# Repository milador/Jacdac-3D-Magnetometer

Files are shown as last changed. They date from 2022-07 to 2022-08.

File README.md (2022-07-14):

# Jacdac-3D-Magnetometer
A <a href="https://microsoft.github.io/jacdac-docs/">Jacdac</a> 3D-Magnetometer Module based on <a href="https://www.infineon.com/cms/en/product/sensor/magnetic-sensors/magnetic-position-sensors/3d-magnetics/tlv493d-a1b6/">TLV493D</a> 3-axis magnetometer sensor.

## Top View: 

<p align="center">
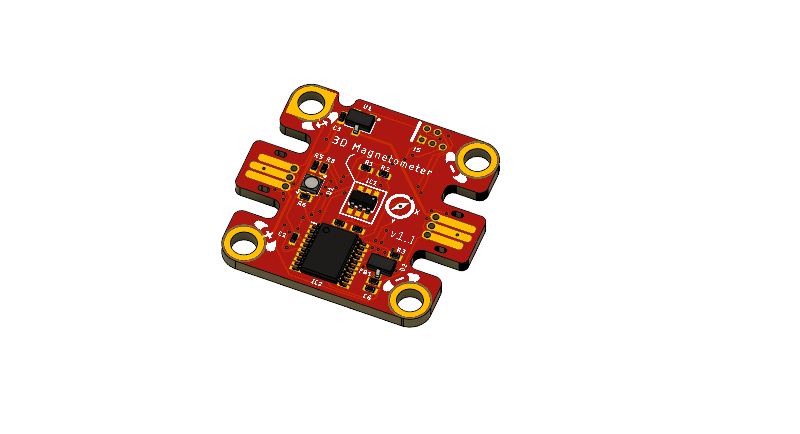
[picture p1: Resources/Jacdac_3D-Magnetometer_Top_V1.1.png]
Jacdac-3D-Magnetometer Top

</p>

## Bottom View:

<p align="center">
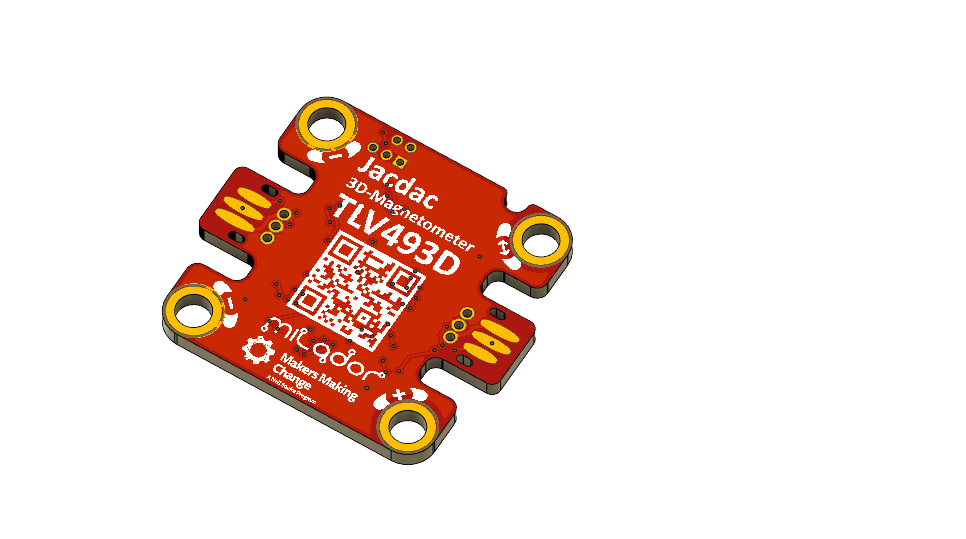
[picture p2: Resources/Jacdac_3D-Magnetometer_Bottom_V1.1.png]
Jacdac-3D-Magnetometer Bottom

</p>

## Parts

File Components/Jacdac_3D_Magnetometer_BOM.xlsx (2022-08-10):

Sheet: RevA
Index | Quantity | Item | Value | Digikey/Mouser/LCSC Part Number | Manufacturer Part Number | Description | Unit Price (CAD) | Total Price (CAD) | Link
1 | 2 | R1,R2 | 30R | C136965 | RT0603BRD0730RL | RES 30 OHM 1% 1/8W 0603 | 0.0344 | 0.0688 | https://lcsc.com/product-detail/Chip-span-style-background-color-ff0-Resistor-span-Surface-Mount_YAGEO-RT0603BRD0730RL_C136965.html
2 | 1 | R3 | 150R | C319859 | AR03BTCX1500 | RES 150 OHM 1% 1/8W 0603 | 0.037 | 0.037 | https://lcsc.com/product-detail/Chip-Resistor-Surface-Mount_Viking-Tech-AR03BTCX1500_C319859.html
3 | 1 | R4 | 220R | C318124 | AR03BTCX2200 | RES SMD 220 OHM 5% 1/8W 0603 | 0.029 | 0.029 | https://lcsc.com/product-detail/Chip-Resistor-Surface-Mount_Viking-Tech-AR03BTCX2200_C318124.html
4 | 2 | R5,R6 | 4.7K | C700513 | RT0603FRE074K7L | RES 4.7K OHM 1% 1/8W 0603 | 0.0089 | 0.0178 | https://lcsc.com/product-detail/Chip-Resistor-Surface-Mount_YAGEO-RT0603FRE074K7L_C700513.html
5 | 1 | U1 | STM32F042F6P6 | C81000 | STM32F042F6P6 | IC MCU 32BIT 32KB FLASH 20TSSOP | 7.33 | 7.33 | https://lcsc.com/product-detail/ST-Microelectronics_STMicroelectronics-STM32F042F6P6_C81000.html
6 | 1 | U2 | NCP114ASN330T1G | NCP114ASN330T1GOSCT-ND/C457666 | NCP114ASN330T1G | IC REG LINEAR 3.3V 300MA 5TSOP | 0.2352 | 0.2352 | https://lcsc.com/product-detail/Linear-Voltage-Regulators-LDO_onsemi-NCP114ASN330T1G_C457666.html (https://www.digikey.ca/en/products/detail/on-semiconductor/NCP114ASN330T1G/6560605)
7 | 1 | U3 | TLV493DA1B6 | 726-TLV493DA1B6HTSA2 /C126688 | TLV493DA1B6HTSA2 | 3D-MAGNETOMETER | 3.27 | 3.27 | https://www.mouser.ca/ProductDetail/Infineon-Technologies/TLV493DA1B6HTSA2?qs=0DP5yvOrqYnbdRXsuslLCg%3D%3D | https://lcsc.com/product-detail/Magnetic-Sensors_Infineon-Technologies-TLV493DA1B6HTSA2_C126688.html
8 | 1 | U4 | BAT54S,235 | C503463 | BAT54S,235 | DIODE ARRAY SCHOTTKY 30V SOT23 | 0.03 | 0.03 | https://lcsc.com/product-detail/Pre-ordered-transistors_Nexperia-BAT54S-235_C503463.html
9 | 3 | C1,C3,C5 | 1uF | C519560 | CC0603JRX7R7BB105 | CAP CER 1UF 16V X5R 0603 | 0.0284 | 0.0852 | https://lcsc.com/product-detail/Multilayer-Ceramic-Capacitors-MLCC-SMD-SMT_YAGEO-CC0603JRX7R7BB105_C519560.html
10 | 1 | C2 | 33pF | C519485 | CC0603FRNPO9BN330 | CAP CER 0603 33PF 50V ULTRA STAB | 0.0177 | 0.0177 | https://lcsc.com/product-detail/Multilayer-Ceramic-Capacitors-MLCC-SMD-SMT_YAGEO-CC0603FRNPO9BN330_C519485.html
11 | 1 | C4 | 0.1 µF | C1845757 | C0603C104M3RACAUTO | CAP CER 0.1UF 25V X7R 0603 | 0.018 | 0.018 | https://lcsc.com/product-detail/Multilayer-Ceramic-Capacitors-MLCC-SMD-SMT_KEMET-C0603C104M3RACAUTO_C1845757.html
12 | 1 | FB1 | 800mA 1kR | C193411 | MPZ1608S102ATD25 | FERRITE BEAD 1 KOHM 0603 1LN | 0.028 | 0.028 | https://lcsc.com/product-detail/Ferrite-Beads_TDK-MPZ1608S102ATD25_C193411.html
13 | 2 | D1,D2 | RCLAMP0521P | C2827711 | RCLAMP0521P | TVS DIODE 5VWM 25VC SLP1006P2 | 0.0445 | 0.089 | https://lcsc.com/product-detail/ESD-Protection-Devices_TECH-PUBLIC-RCLAMP0521P_C2827711.html
14 | 1 | LED (D3) | RGB LED | 516-1795-1-ND /C97504 | HSMF-C114 | LED RGB DIFFUSED CHIP SMD | 2.63 | 2.63 | https://www.digikey.ca/en/products/detail/broadcom-limited/HSMF-C114/1235344
 |  |  |  |  |  |  | Total Price: | 13.8857

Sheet: RevB
Index | Quantity | Item | Value | Digikey/Mouser/LCSC Part Number | Manufacturer Part Number | Description | Unit Price (CAD) | Total Price (CAD) | Link
1 | 2 | R1,R2 | 10K | C2902636 | ARG02BTC1002 | RES 10K OHM 0.1% 0402 | 0.0233 | 0.0466 | https://lcsc.com/product-detail/Chip-Resistor-Surface-Mount_Viking-Tech-ARG02BTC1002_C2902636.html
2 | 2 | R3,R5 | 220R | C317911 | AR02BTC2200 | RES 220 OHM 0.1% 0402 | 0.0272 | 0.0544 | https://lcsc.com/product-detail/Chip-Resistor-Surface-Mount_Viking-Tech-AR02BTC2200_C317911.html
3 | 1 | R6 | 470R | C482182 | CRCW0402470RFKED | RES 470 OHM 1% 0402 | 0.0394 | 0.0394 | https://lcsc.com/product-detail/Chip-Resistor-Surface-Mount_Vishay-Intertech-CRCW0402470RFKED_C482182.html
4 | 1 | R8 | 150R | C319855 | AR02BTC1500 | RES 150 OHM 0.1% 0402 | 0.032 | 0.032 | https://lcsc.com/product-detail/Chip-Resistor-Surface-Mount_Viking-Tech-AR02BTC1500_C319855.html
5 | 1 | IC1 | TLV493DA1B6 | TLV493DA1B6HTSA2/C126688 | TLV493DA1B6HTSA2 | 3D-MAGNETOMETER | 3.27 | 3.27 | https://www.arrow.com/en/products/tlv493da1b6htsa2/infineon-technologies-ag?q=TLV493DA1B6HTSA2 | https://lcsc.com/product-detail/Magnetic-Sensors_Infineon-Technologies-TLV493DA1B6HTSA2_C126688.html
6 | 1 | IC2 | STM32G030F6P6 | C724040 | STM32G030F6P6 | IC MCU 32BIT 32KB FLASH 20TSSOP | 0.98 | 0.98 | https://lcsc.com/product-detail/ST-Microelectronics_STMicroelectronics-STM32G030F6P6_C724040.html
7 | 1 | U1 | XC6206-3.3V | C2891841 | XC6206-3.3V | IC REG LINEAR 3.3V SOT-23-3L | 0.0614 | 0.0614 | https://lcsc.com/product-detail/Linear-Voltage-Regulators-LDO_YONGYUTAI-XC6206-3-3V_C2891841.html
8 | 2 | C1,C4 | 100nF | C361202 | C1005X5R1H104KT000F | 50V 100nF X5R ±10% 0402 | 0.0227 | 0.0454 | https://lcsc.com/product-detail/Multilayer-Ceramic-Capacitors-MLCC-SMD-SMT_TDK-C1005X5R1H104KT000F_C361202.html
9 | 2 | C2,C3 | 4.7uF | C342983 | C1005X5R1A475KTJ00E | 10V 4.7uF X5R ±10% 0402 | 0.0476 | 0.0952 | https://lcsc.com/product-detail/Multilayer-Ceramic-Capacitors-MLCC-SMD-SMT_TDK-C1005X5R1A475KTJ00E_C342983.html
10 | 1 | C6 | 33pF | C76905 | GJM1555C1H330GB01D | 50V 33pF C0G ±2% 0402 | 0.0335 | 0.0335 | https://lcsc.com/product-detail/Multilayer-Ceramic-Capacitors-MLCC-SMD-SMT_Murata-Electronics-GJM1555C1H330GB01D_C76905.html
11 | 1 | FB1 | 1kΩ @ 100MHz | C275423 | MMZ1005S102ET000 | FERRITE BEAD 250mA 1 1Ω 1kΩ@100MHz ±25% 0402 | 0.0308 | 0.0308 | https://lcsc.com/product-detail/Ferrite-Beads_TDK-MMZ1005S102ET000_C275423.html
12 | 1 | D1 | RGB LED | C108793 | FM-B2020RGBA-HG | LED RGB CHIP SMD | 0.0289 | 0.0289 | https://lcsc.com/product-detail/Light-Emitting-Diodes-LED_Foshan-NationStar-Optoelectronics-FM-B2020RGBA-HG_C108793.html
13 | 1 | D2 | BAT54S | C328578 | BAT54S,23 | DIODE ARRAY SCHOTTKY 30V SOT23 | 0.0245 | 0.0245 | https://lcsc.com/product-detail/Schottky-Barrier-Diodes-SBD_Foshan-Blue-Rocket-Elec-BAT54S_C328578.html
 |  |  |  |  |  |  | Total Price: | 4.7421

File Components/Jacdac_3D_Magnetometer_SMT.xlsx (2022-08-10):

Item | Additional Information | Cost
PCB (Jacdac 3D Magnetometer)
PCB fabrication |  | $4.00
Remove order number |  | $1.66
Confirm production file |  | $0.54
SMT
Components | Global Sourcing not included ( Digikey, Mouser) | $9.93
Global Sourcing Components | 5 X $0.8853 (TLV493DA1B6HTSA2) | $4.43
Extended Components fee | $3 labour fee to replace each part in the machine | $38.09
SMT Assembly | $0.0017 per solder joint | $0.97
Setup fee |  | $8.00
Stencil |  | $1.50
Confirm parts placement |  | $0.46
 | Total | $69.58
 | Charged | $69.12

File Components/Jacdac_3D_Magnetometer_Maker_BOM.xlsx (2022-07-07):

Index | Quantity | Item | Value | Digikey/Mouser Part Number | Manufacturer Part Number | Description | Unit Price (CAD) | Total Price (CAD) | Link
1 | 2 | R1,R2 | 30R | 311-30.0CRCT-ND | RC0805FR-0730RL | RES 30 OHM 1% 1/8W 0805 | 0.15 | 0.3 | https://www.digikey.ca/en/products/detail/yageo/RC0805FR-0730RL/727842
2 | 1 | R3 | 150R | 541-CRCW0805150RFKEACCT-ND | CRCW0805150RFKEAC | RES 150 OHM 1% 1/8W 0805 | 0.15 | 0.15 | https://www.digikey.ca/en/products/detail/vishay-dale/CRCW0805150RFKEAC/7922303
3 | 1 | R4 | 220R | 541-CRCW0805220RJNEBCT-ND | CRCW0805220RJNEB | RES SMD 220 OHM 5% 1/8W 0805 | 0.15 | 0.15 | https://www.digikey.ca/en/products/detail/vishay-dale/CRCW0805220RJNEB/5074408
4 | 2 | R5,R6 | 4.7K | 311-4.7KARCT-ND | RC0805JR-074K7L | RES 4.7K OHM 5% 1/8W 0805 | 0.15 | 0.3 | https://www.digikey.ca/en/products/detail/yageo/RC0805JR-074K7L/728327
5 | 1 | U1 | STM32F042F6P6 | 497-17344-ND | STM32F042F6P6 | IC MCU 32BIT 32KB FLASH 20TSSOP | 4.66 | 4.66 | https://www.digikey.ca/en/products/detail/stmicroelectronics/STM32F042F6P6/5268189
6 | 1 | U2 | NCP114ASN330T1G | NCP114ASN330T1GOSCT-ND | NCP114ASN330T1G | IC REG LINEAR 3.3V 300MA 5TSOP | 0.57 | 0.57 | https://www.digikey.ca/en/products/detail/on-semiconductor/NCP114ASN330T1G/6560605
7 | 1 | U3 | TLV493DA1B6 | 726-TLV493DA1B6HTSA2 | TLV493DA1B6HTSA2 | 3D-MAGNETOMETER | 3.27 | 3.27 | https://www.mouser.ca/ProductDetail/Infineon-Technologies/TLV493DA1B6HTSA2?qs=0DP5yvOrqYnbdRXsuslLCg%3D%3D
8 | 1 | U4 | BAT54S,235 | 1727-1868-1-ND | BAT54S,235 | DIODE ARRAY SCHOTTKY 30V SOT23 | 0.2 | 0.2 | https://www.digikey.ca/en/products/detail/nexperia-usa-inc/BAT54S-235/1232122
9 | 3 | C1,C3,C5 | 1uF | 478-1249-1-ND | 0603YD105KAT2A | CAP CER 1UF 16V X5R 0603 | 0.18 | 0.54 | https://www.digikey.ca/en/products/detail/avx-corporation/0603YD105KAT2A/563359
10 | 1 | C2 | 33pF | 399-C0603C330M5HAC7867CT-ND | C0603C330M5HAC7867 | CAP CER 0603 33PF 50V ULTRA STAB | 0.14 | 0.14 | https://www.digikey.ca/en/products/detail/kemet/C0603C330M5HAC7867/7947133
11 | 1 | C4 | 0.1 µF | 478-3755-1-ND | 08053C104KAT2A | CAP CER 0.1UF 25V X7R 0805 | 0.14 | 0.14 | https://www.digikey.ca/en/products/detail/avx-corporation/08053C104KAT2A/1116281?
12 | 1 | FB1 | 800mA 1kR | 445-175021-1-ND | KPZ1608SHR102ATD25 | FERRITE BEAD 1 KOHM 0603 1LN | 0.3 | 0.3 | https://www.digikey.ca/en/products/detail/tdk-corporation/KPZ1608SHR102ATD25/7104424
13 | 1 | LED (D1) | RGB LED | 516-1795-1-ND | HSMF-C114 | LED RGB DIFFUSED CHIP SMD | 2.63 | 2.63 | https://www.digikey.ca/en/products/detail/broadcom-limited/HSMF-C114/1235344
 |  |  |  |  |  |  | Total Price: | 13.35

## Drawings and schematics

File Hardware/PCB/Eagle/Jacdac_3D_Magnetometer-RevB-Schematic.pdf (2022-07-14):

# GND GND 1k@¹⁰⁰MHz VCC

# JD5V VCC

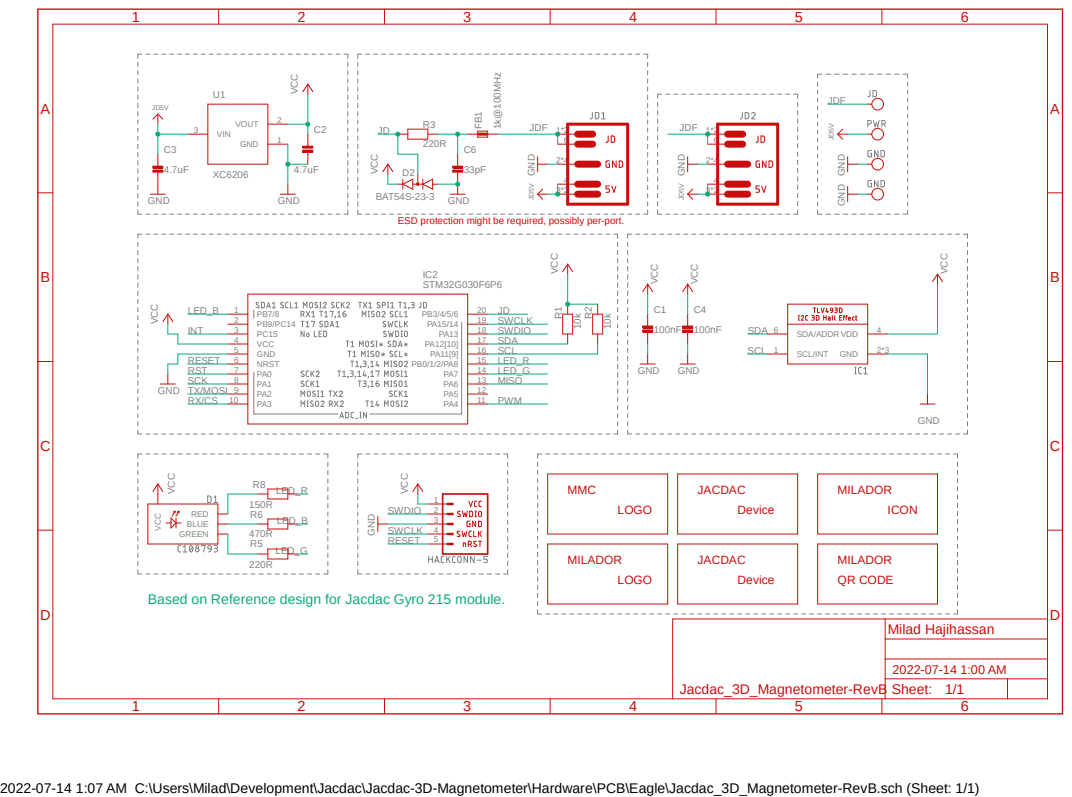
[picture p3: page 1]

ESD protection might be required, possibly per-port.

Based on Reference design for Jacdac Gyro 215 module.

2022-07-14 1:07 AM C:\Users\Milad\Development\Jacdac\Jacdac-3D-Magnetometer\Hardware\PCB\Eagle\Jacdac_3D_Magnetometer-RevB.sch (Sheet: 1/1)

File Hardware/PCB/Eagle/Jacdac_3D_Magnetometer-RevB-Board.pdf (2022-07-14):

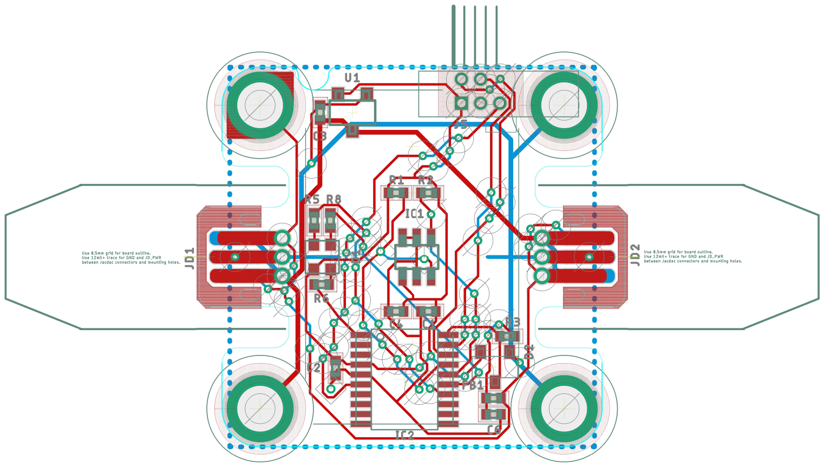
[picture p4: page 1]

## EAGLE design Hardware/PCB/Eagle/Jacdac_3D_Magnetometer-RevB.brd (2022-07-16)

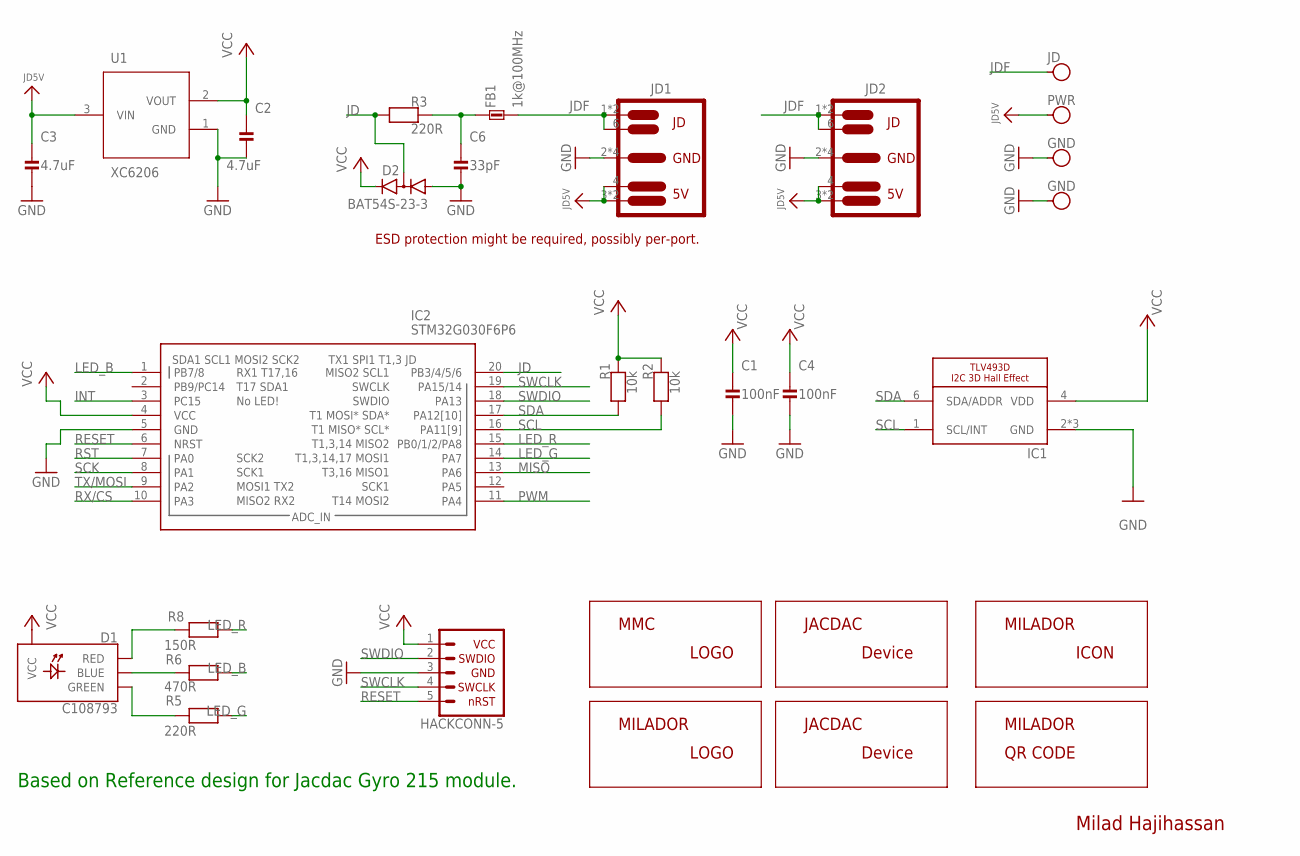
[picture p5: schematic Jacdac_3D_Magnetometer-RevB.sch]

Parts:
C1, C4: 100nF; 0402
C2, C3: 4.7uF; 0402
C6: 33pF; 0402
D1: C108793; LED-RGB-2121
D2: BAT54S-23-3; SOT23-3
FB1: 1k@100MHz; 0402
IC1: TLV493D; SOT23-6
IC2: STM32G030F6P6; SOP65P640X120-20N
J1: JD; M3-HOLE-DATA
J2: PWR; M3-HOLE-PWR
J3, J4: GND; M3-HOLE-GND
J5: HACK-CONNECT-5; HC5-22-62
JD1, JD2: JACDAC-EDGE-OUTIE; JD-EDGE-OUTIE
LABEL_DEVICE: MILADOR-JACDAC-DEVICE-MAGNETOMETER; JACDAC-3D-MAGNETOMETER
LABEL_ICON: MILADOR-ICON-MAG; MILADOR_ICON_MAGNETOMETER
LABEL_LOGO1: MILADOR-LOGO-SM; MILADOR_LOGO2
LABEL_LOGO2: MMC_LOGO-XSM; MMC_X-SMALL_LOGO
LABEL_QRCODE: MILADOR-QR-CODE-JACDAC-MAGNETOMETER; MILADOR_QR_JACDAC_MAGNETOMETER
LABEL_TLV493D: MILADOR-JACDAC-DEVICE-TLV493D; JACDAC-TLV493D
R1, R2: 10k; 0402
R3, R5: 220R; 0402
R6: 470R; 0402
R8: 150R; 0402
U1: XC6206; SOT23-3-W

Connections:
GND: C1.2, C2.2, C3.2, C4.2, C6.2, D2.1 (A1), IC1.2 (GND), IC1.3 (GND), IC1.5 (GND), IC2.5 (GND), J3.H, J4.H, J5.3 (GND), JD1.2 (1), JD1.5 (1), JD1.P$2 (1), JD1.P$4 (1), JD2.2 (1), JD2.5 (1), JD2.P$2 (1), JD2.P$4 (1), U1.1 (GND)
INT: IC2.3 (PC15)
JD: D2.3 (C1A2), IC2.20 (PB3/4/5/6), R3.1
JD5V: C3.1, J2.H, JD1.3, JD1.4, JD1.P$1 (3), JD2.3, JD2.4, JD2.P$1 (3), U1.3 (VIN)
JDF: FB1.2, J1.H, JD1.1 (2), JD1.6, JD1.P$3 (2), JD2.1 (2), JD2.6, JD2.P$3 (2)
LED_B: IC2.1 (PB7/8), R6.1
LED_G: IC2.14 (PA7), R5.1
LED_R: IC2.15 (PB0/1/2/PA8), R8.1
MISO: IC2.13 (PA6)
unnamed: C6.1, FB1.1, R3.2
unnamed: D1.B- (BLUE), R6.2
unnamed: D1.R- (RED), R8.2
unnamed: D1.G- (GREEN), R5.2
PWM: IC2.11 (PA4)
RESET: IC2.6 (NRST), J5.5 (NRST)
RST: IC2.7 (PA0)
RX/CS: IC2.10 (PA3)
SCK: IC2.8 (PA1)
SCL: IC1.1 (SCL/INT), IC2.16 (PA11[9]), R2.1
SDA: IC1.6 (SDA/ADDR), IC2.17 (PA12[10]), R1.1
SWCLK: IC2.19 (PA15/14), J5.4 (SWCLK)
SWDIO: IC2.18 (PA13), J5.2 (SWDIO)
TX/MOSI: IC2.9 (PA2)
VCC: C1.1, C2.1, C4.1, D1.PLUS (VCC), D2.2 (C2), IC1.4 (VDD), IC2.4 (VCC), J5.1 (VCC), R1.2, R2.2, U1.2 (VOUT)

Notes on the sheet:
Based on Reference design for Jacdac Gyro 215 module.
ESD protection might be required, possibly per-port.
Milad Hajihassan

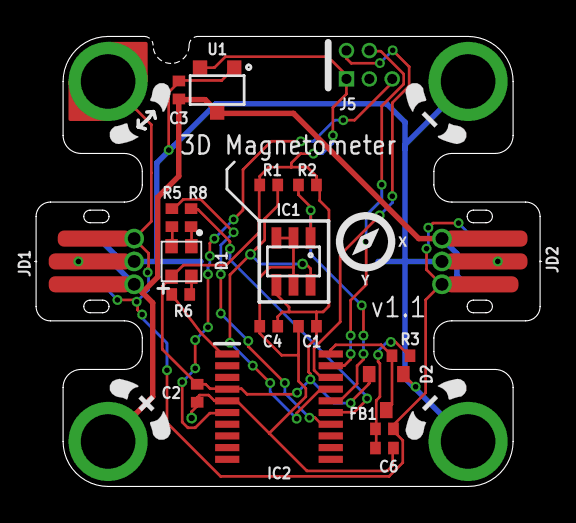
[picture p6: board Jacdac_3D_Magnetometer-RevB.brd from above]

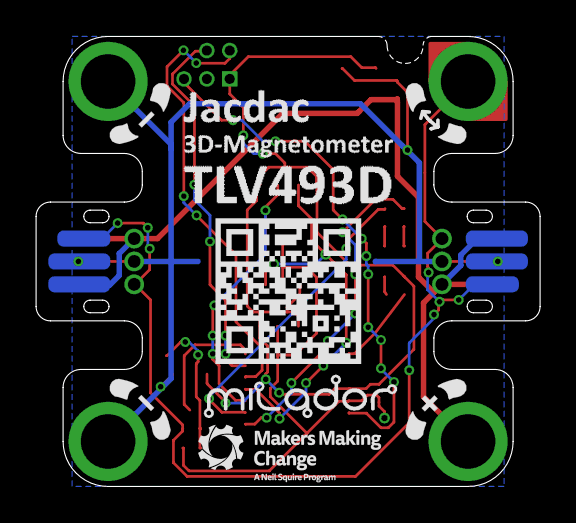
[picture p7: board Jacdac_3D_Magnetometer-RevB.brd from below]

Board: 2 copper layers, 28.0 x 25.0 mm, 30 parts (5 on the bottom side), 17 nets.

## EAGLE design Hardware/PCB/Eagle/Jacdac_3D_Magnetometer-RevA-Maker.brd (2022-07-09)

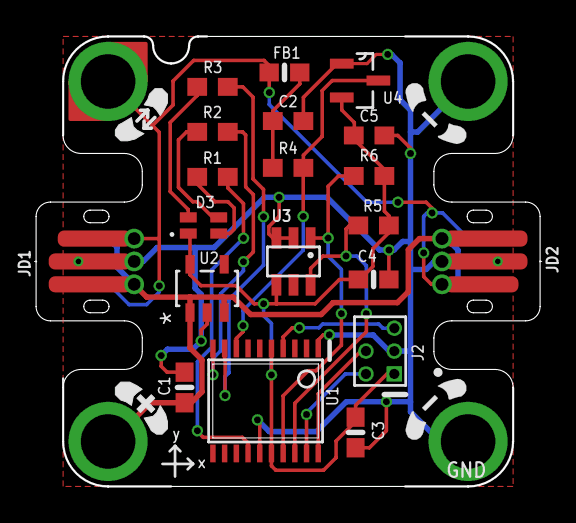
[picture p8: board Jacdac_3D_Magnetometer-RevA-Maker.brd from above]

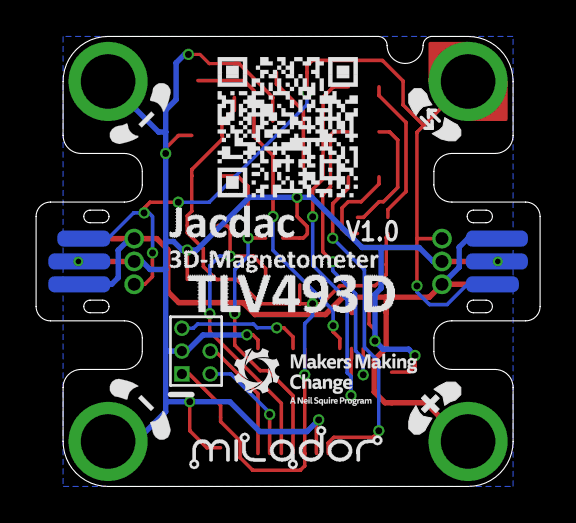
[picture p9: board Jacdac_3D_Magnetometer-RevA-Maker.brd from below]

Board: 2 copper layers, 28.0 x 25.0 mm, 29 parts (5 on the bottom side), 17 nets.

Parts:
C1, C3: 1uF; 0603-NO
C2: 33pF; 0603
C4: 0.1uF; 0603-NO
C5: 1uF; 0603
D3: LED-HSMF-C114; DIOSC160X150X35-4N
FB1: 800mA 1kR; 0603-NO
J2: SWD-ADAPTER-; SWD-ADAPTER
J3: 5V; M3-HOLE-PWR-OUTL
J4: DATA; M3-HOLE-DATA-NOTCH
J5, J6: GND; M3-HOLE-GND
JD1, JD2: JACDAC-EDGE-OUTIE; JD-EDGE-OUTIE
LABEL_JACDAC_PS: MILADOR-JACDAC-DEVICE-MAGNETOMETER; JACDAC-3D-MAGNETOMETER
LABEL_MILADOR: MILADOR-LOGO-; MILADOR_LOGO1
LABEL_QR_CODE: MILADOR-QR-CODE-JACDAC-MAGNETOMETER; MILADOR_QR_JACDAC_MAGNETOMETER
LABEL_TLV493D: MILADOR-JACDAC-DEVICE-TLV493D; JACDAC-TLV493D
MMC_LOGO: MMC_LOGO-XSM; MMC_X-SMALL_LOGO
R1, R2: 30; 0603
R3: 150; 0603
R4: 220; 0603
R5, R6: 4.7K; 0603
U1: STM32F042F6P6; TSSOP20
U2: NCP114ASN330T1G; TSOP-5_ONS
U3: TLV493D; SOT23-6
U4: BAT54S,235; SOT23-3

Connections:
+3V3: C3.1, C4.1, C5.1, D3.1, J2.1, R5.2, R6.2, U1.5, U1.16, U2.5, U3.4, U4.2
GND: C1.2, C2.2, C3.2, C4.2, C5.2, J2.3, J5.H, J6.H, JD1.2, JD1.5, JD1.P$2, JD1.P$4, JD2.2, JD2.5, JD2.P$2, JD2.P$4, U1.1, U1.15, U2.2, U3.2, U3.3, U3.5, U4.1
JD5V: C1.1, J3.H, JD1.3, JD1.4, JD1.P$1, JD2.3, JD2.4, JD2.P$1, U2.1, U2.3
JD_DATA: R4.2, U1.8, U4.3
J_DATA: FB1.2, J4.H, JD1.1, JD1.6, JD1.P$3, JD2.1, JD2.6, JD2.P$3
unnamed: D3.4, R1.1
unnamed: D3.3, R2.1
unnamed: D3.2, R3.1
unnamed: C2.1, FB1.1, R4.1
RESET: J2.5, U1.4
RGB_B: R1.2, U1.14
RGB_G: R2.2, U1.10
RGB_R: R3.2, U1.9
SCL: R6.1, U1.17, U3.1
SDA: R5.1, U1.18, U3.6
SWCLK: J2.4, U1.20
SWDIO: J2.2, U1.19

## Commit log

2022-07-06 Added version 1.0 design files
    [Jacdac_3D_Magnetometer.brd, Jacdac_3D_Magnetometer.sch, Jacdac_3D_Magnetometer_BOM.xlsx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]
2022-07-07 Added RevB
    [Jacdac_3D_Magnetometer-RevB.brd, Jacdac_3D_Magnetometer_BOM.xlsx, Jacdac_3D_Magnetometer_Maker_BOM.xlsx]
2022-07-08 Updated BOM
    [Jacdac_3D_Magnetometer_BOM.xlsx]
2022-07-09 Updated RevB
    [Jacdac_3D_Magnetometer-RevA-Maker.brd, Jacdac_3D_Magnetometer-RevA.brd, Jacdac_3D_Magnetometer.brd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]
2022-07-13 Updated RevB design to match pinouts of other Jacdac modules
    [Jacdac_3D_Magnetometer-RevB.brd]
2022-07-14 Updated board.pdf
2022-07-14 Updated components value
    [Jacdac_3D_Magnetometer-RevB.brd, Jacdac_3D_Magnetometer-RevB.sch]
2022-07-16 Updated Magnetometer icon
    [Jacdac_3D_Magnetometer-RevB.brd, Jacdac_3D_Magnetometer-RevB.sch]
2022-08-10 Updated BOM for SMT
    [Jacdac_3D_Magnetometer-RevB.sch, Jacdac_3D_Magnetometer_BOM.xlsx, Jacdac_3D_Magnetometer_RevB_BOM.xlsx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]

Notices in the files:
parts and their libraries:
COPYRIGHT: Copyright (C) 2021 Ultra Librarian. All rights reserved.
